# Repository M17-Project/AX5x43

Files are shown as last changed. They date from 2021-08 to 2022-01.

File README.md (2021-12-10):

# AX5x43
Test boards for the ON Semiconductor AX5043 and AX5243 RF transceiver chips.
#### The main purpose of this board is to test AX5x43's M17 support.

### Main differences between our board and other available out there
There are two major differences:
- the PWRAMP (AX5043) or TCXO_EN (AX5243) pin can be used as a sigma-delta modulator output for analog demodulation
- GPADC1 and GPADC2 pins can be used for analog frequency modulation (a VCO mode, if you will)

Note: There are no additional operational amplifiers nor filters in our design. Both modulator input and output are available at the pin header. ADC inputs can work in both differential and single-ended modes. Refer to the application note [AND9313/D](https://www.onsemi.com/pub/collateral/and9313-d.pdf).

### AX5043 PCB
PCB

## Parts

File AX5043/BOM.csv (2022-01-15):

References | Qty | Description | Manufacturer | MPN
C1 | 1 | 10pF 0603 | Yageo | CC0603JRNPO9BN100
C2 | 1 | 6.8pF 0603 | Yageo | CC0603DRNPO9BN6R8
C3 C4 | 2 | 100pF 0603 | Yageo | CC0603JRNPO9BN101
C5 C6 | 2 | 4.3pF 0603 | Yageo | CC0603CRNPO9BN4R3
C7 | 1 | 11pF 0603 | Yageo | CC0603JPNPO9BN110
C8 | 1 | 5.6pF 0603 | Yageo | CC0603DRNPO9BN5R6
C9 | 1 | 5.1pF 0603 | Yageo | CC0603CRNPO9BN5R1
C10 C12 C15 | 3 | 10nF 0603 | Yageo | CC0603KRX7R9BB103
C11 C13 | 2 | 100nF 0603 | Yageo | CC0603KRX7R9BB104
C14 | 1 | 39pF 0603 | Yageo | CC0603JRNPO9BN390
JP1 | 1 | CPL-CON-HEADER-THT-MALE
R1 R2 | 2 | 100nH 0603 | Murata | LQW18ASR10G00D
R3 R4 | 2 | 43nH 0603 | Murata | LQW18AN43NG00D
R5 R6 | 2 | 27nH 0603 | Murata | LQW18AN27NG00D
R9 | 1 | 6.8nH 0603 | Murata | LQW18AN6N8C00D
R10 | 1 | 12k 0603 | Yageo | RC0603FR-0712KL
U1 | 1 | AX5043 | onsemi | AX5043-1-TW30
X1 | 1 | 12MHz TCXO 2520 | ECS | ECS-TXO-2520MV-120-AY-TR
X2 | 1 | SMA female connector PCB edge mount | RF Solutions | CON-SMA-EDGE-S

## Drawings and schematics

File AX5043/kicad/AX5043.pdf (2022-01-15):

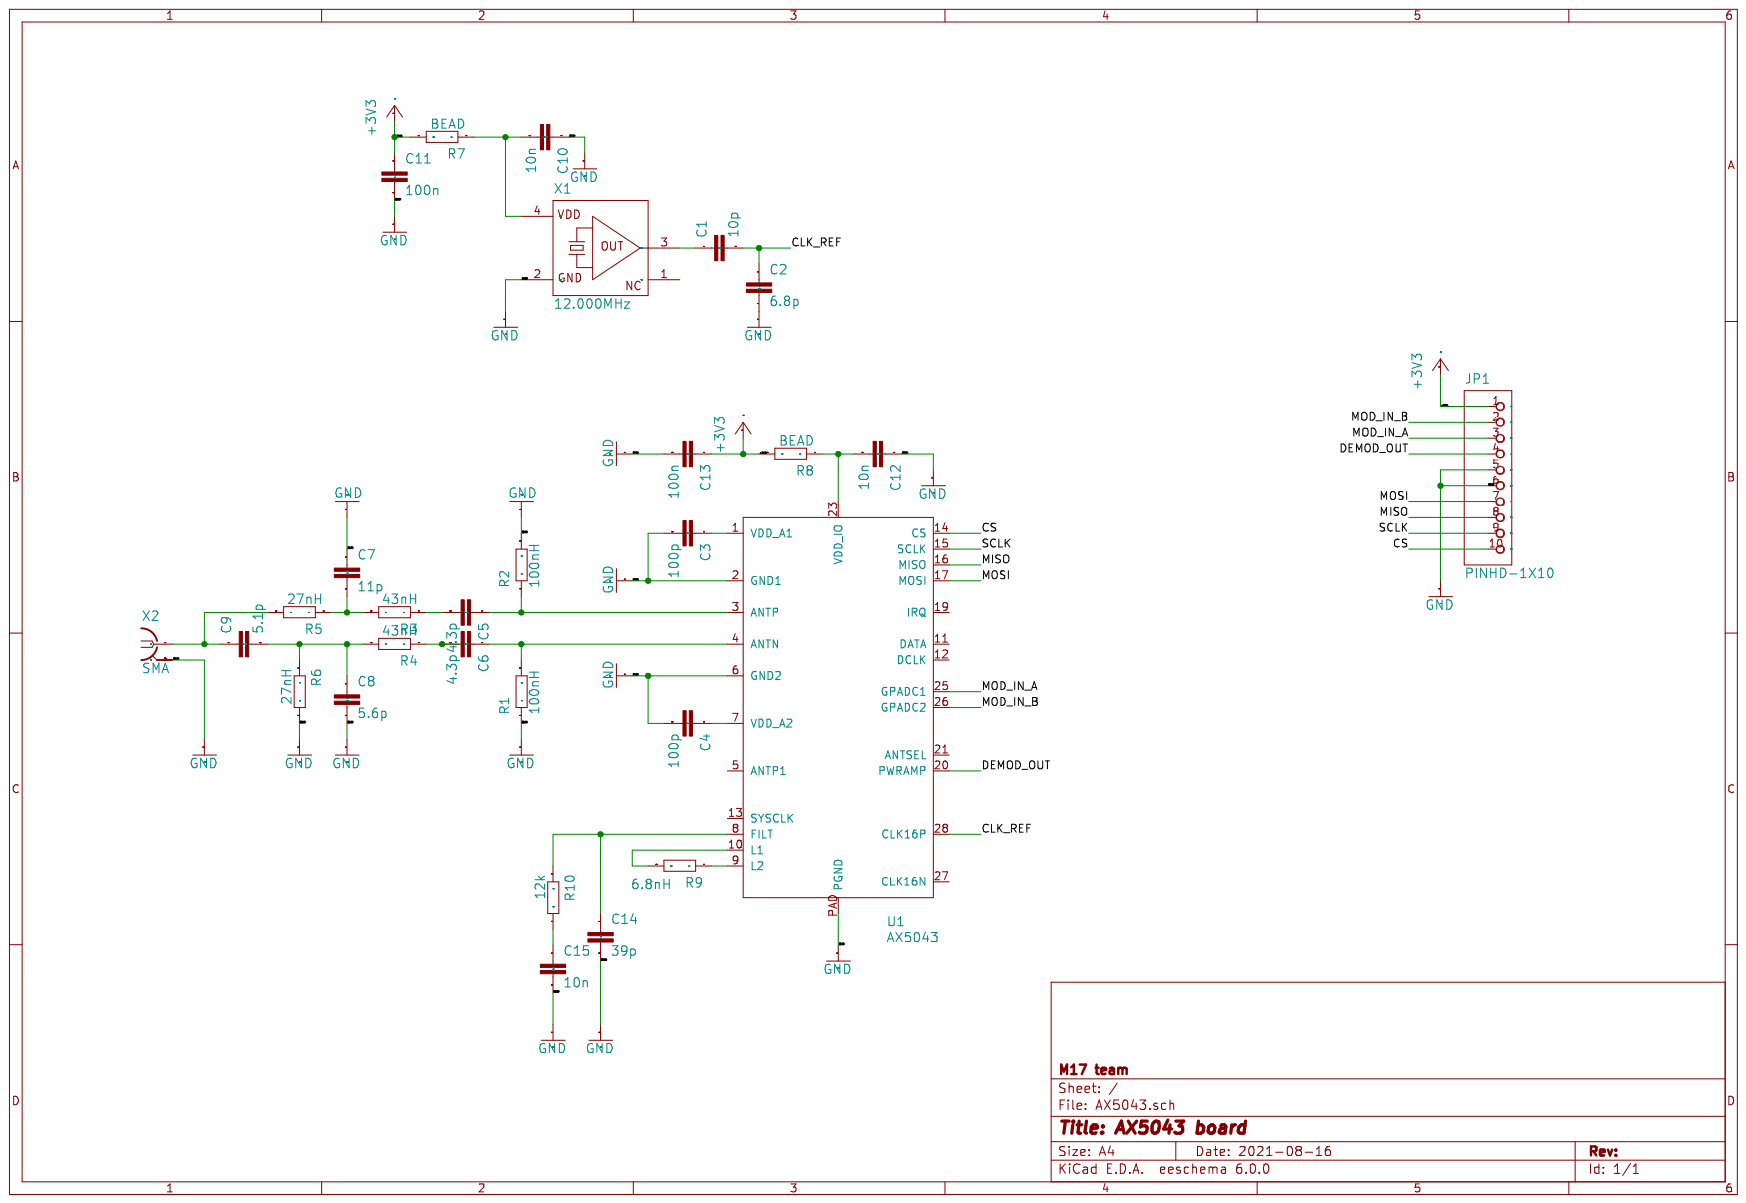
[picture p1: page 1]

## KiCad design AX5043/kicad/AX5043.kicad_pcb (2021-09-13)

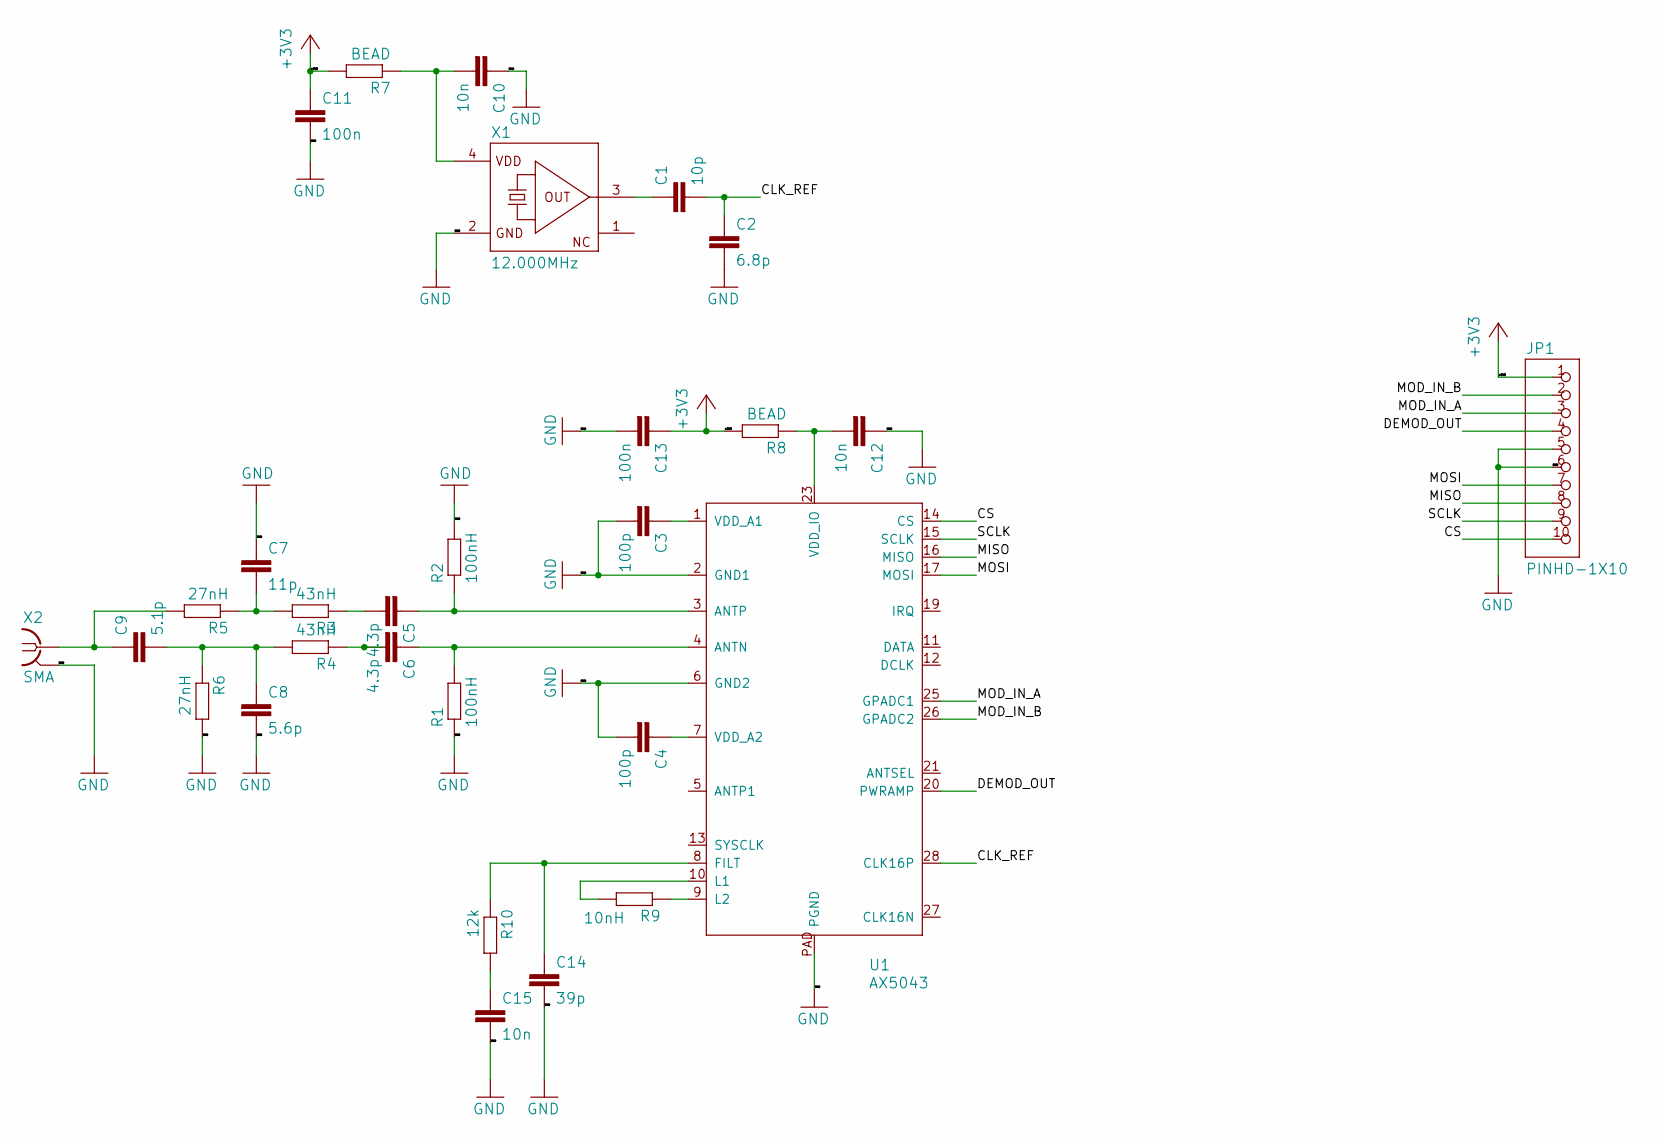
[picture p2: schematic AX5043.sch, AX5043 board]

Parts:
C1: 10p; C0603
C2: 6.8p; C0603
C3, C4: 100p; C0603
C5, C6: 4.3p; C0603
C7: 11p; C0603
C8: 5.6p; C0603
C9: 5.1p; C0603
C10, C12, C15: 10n; C0603
C11, C13: 100n; C0603
C14: 39p; C0603
JP1: PINHD-1X10; 1X10
R1, R2: 100nH; R0603
R3, R4: 43nH; R0603
R5, R6: 27nH; R0603
R7, R8: BEAD; R0603
R9: 10nH; R0603
R10: 12k; R0603
U1: AX5043; QFN28-5X5-WITH-CENTER-PAD
X1: 12.000MHz; ECS-TXO-2520
X2: SMA; J502-ND-142-0711-821_826

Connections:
+3V3: C11.1, C13.1, JP1.1, R7.2, R8.2
/CLK_REF: C1.2, C2.1, U1.28 (CLK16P)
/CS: JP1.10, U1.14 (CS)
/DEMOD_OUT: JP1.4, U1.20 (PWRAMP)
/MISO: JP1.8, U1.16 (MISO)
/MOD_IN_A: JP1.3, U1.25 (GPADC1)
/MOD_IN_B: JP1.2, U1.26 (GPADC2)
/MOSI: JP1.7, U1.17 (MOSI)
/SCLK: JP1.9, U1.15 (SCLK)
GND: C2.2, C3.2, C4.2, C7.1, C8.2, C10.1, C11.2, C12.1, C13.2, C14.2, C15.2, JP1.5, JP1.6, R1.1, R2.2, R6.2, U1.2 (GND1), U1.6 (GND2), U1.PAD (PGND), X1.2 (GND), X2.G@1 (2), X2.G@2 (2), X2.G@3 (2), X2.G@4 (2)
unnamed: C1.1, X1.3 (OUT)
unnamed: C3.1, U1.1 (VDD_A1)
unnamed: C4.1, U1.7 (VDD_A2)
unnamed: C5.1, R2.1, U1.3 (ANTP)
unnamed: C5.2, R3.1
unnamed: C6.1, R1.2, U1.4 (ANTN)
unnamed: C6.2, R4.1
unnamed: C7.2, R3.2, R5.1
unnamed: C8.1, C9.2, R4.2, R6.1
unnamed: C9.1, R5.2, X2.1
unnamed: C10.2, R7.1, X1.4 (VDD)
unnamed: C12.2, R8.1, U1.23 (VDD_IO)
unnamed: C14.1, R10.1, U1.8 (FILT)
unnamed: C15.1, R10.2
unnamed: R9.1, U1.9 (L2)
unnamed: R9.2, U1.10 (L1)

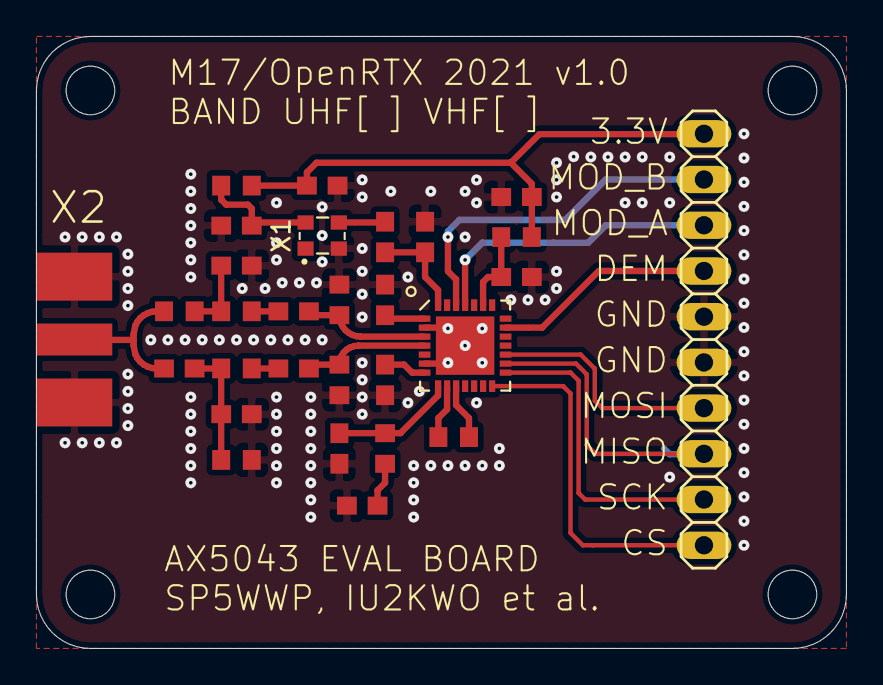
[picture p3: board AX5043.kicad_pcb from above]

Board: 2 copper layers, 45.0 x 34.0 mm, 29 parts (0 on the bottom side), 26 nets.

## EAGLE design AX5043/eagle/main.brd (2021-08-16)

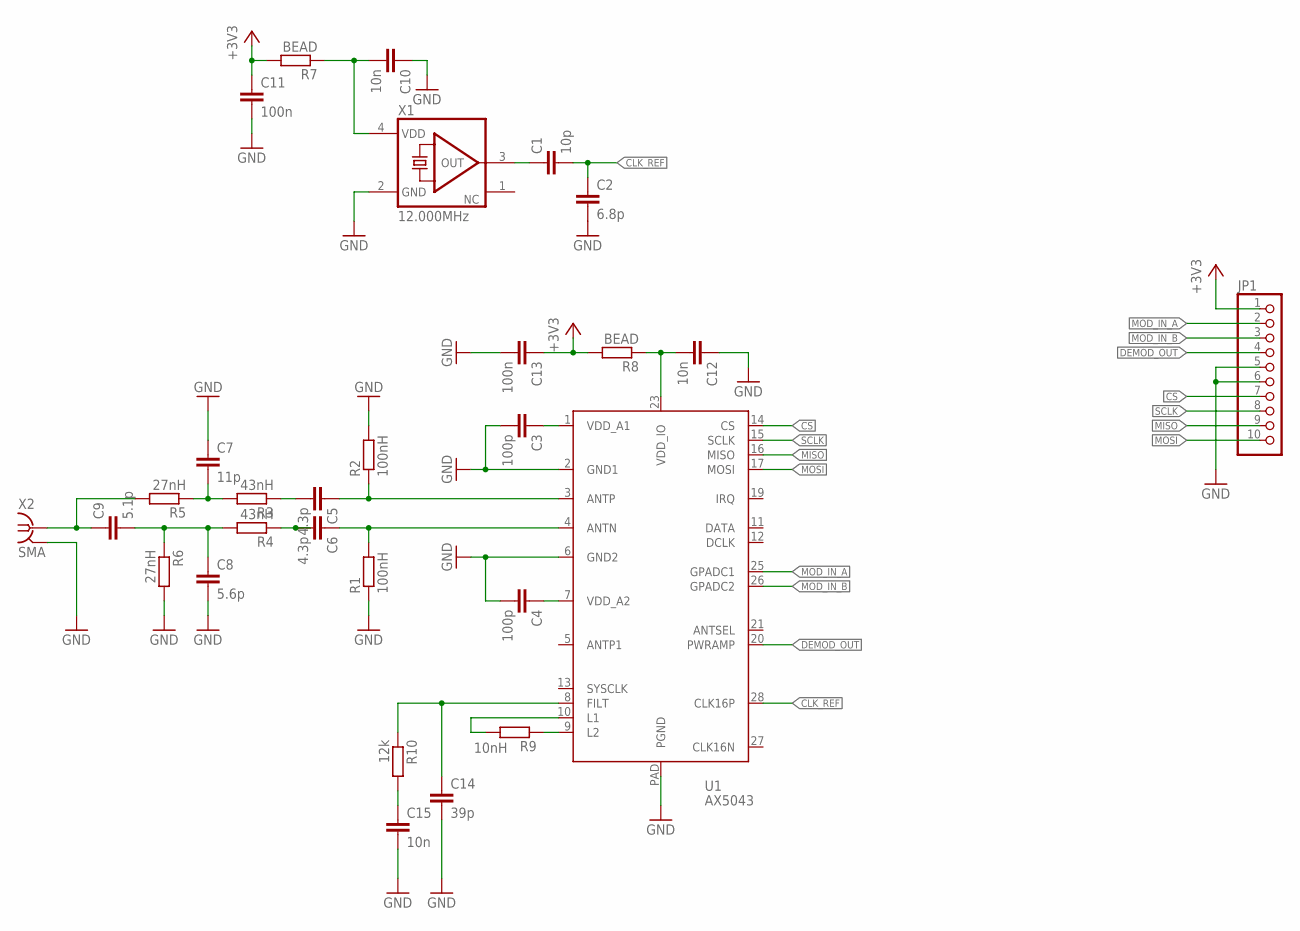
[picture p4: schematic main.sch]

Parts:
C1: 10p; C0603
C2: 6.8p; C0603
C3, C4: 100p; C0603
C5, C6: 4.3p; C0603
C7: 11p; C0603
C8: 5.6p; C0603
C9: 5.1p; C0603
C10, C12, C15: 10n; C0603
C11, C13: 100n; C0603
C14: 39p; C0603
JP1: PINHD-1X10; 1X10
R1, R2: 100nH; R0603
R3, R4: 43nH; R0603
R5, R6: 27nH; R0603
R7, R8: BEAD; R0603
R9: 10nH; R0603
R10: 12k; R0603
U1: AX5043; QFN28-5X5-WITH-CENTER-PAD
X1: 12.000MHz; ASE
X2: SMA; J502-ND-142-0711-821/826

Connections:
+3V3: C11.1, C13.1, JP1.1, R7.2, R8.2
CLK_REF: C1.2, C2.1, U1.28 (CLK16P)
CS: JP1.7, U1.14 (CS)
DEMOD_OUT: JP1.4, U1.20 (PWRAMP)
GND: C2.2, C3.2, C4.2, C7.1, C8.2, C10.1, C11.2, C12.1, C13.2, C14.2, C15.2, JP1.5, JP1.6, R1.1, R2.2, R6.2, U1.2 (GND1), U1.6 (GND2), U1.PAD (PGND), X1.2 (GND), X2.G@1 (2), X2.G@2 (2), X2.G@3 (2), X2.G@4 (2)
MISO: JP1.9, U1.16 (MISO)
MOD_IN_A: JP1.2, U1.25 (GPADC1)
MOD_IN_B: JP1.3, U1.26 (GPADC2)
MOSI: JP1.10, U1.17 (MOSI)
unnamed: C5.1, R2.1, U1.3 (ANTP)
unnamed: C6.1, R1.2, U1.4 (ANTN)
unnamed: C12.2, R8.1, U1.23 (VDD_IO)
unnamed: C6.2, R4.1
unnamed: C4.1, U1.7 (VDD_A2)
unnamed: C3.1, U1.1 (VDD_A1)
unnamed: C1.1, X1.3 (OUT)
unnamed: C5.2, R3.1
unnamed: C10.2, R7.1, X1.4 (VDD)
unnamed: C8.1, C9.2, R4.2, R6.1
unnamed: C7.2, R3.2, R5.1
unnamed: C9.1, R5.2, X2.1
unnamed: R9.1, U1.9 (L2)
unnamed: R9.2, U1.10 (L1)
unnamed: C14.1, R10.1, U1.8 (FILT)
unnamed: C15.1, R10.2
SCLK: JP1.8, U1.15 (SCLK)

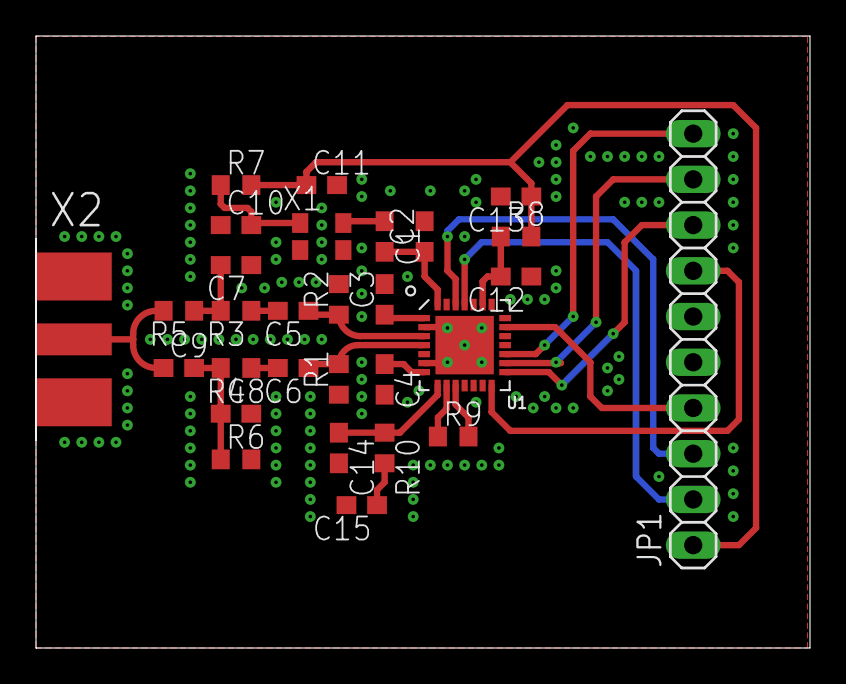
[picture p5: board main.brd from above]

Board: 2 copper layers, 43.0 x 34.0 mm, 29 parts (0 on the bottom side), 26 nets.

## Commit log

2021-08-16 Eagle and KiCad project files
    [AX5043.kicad_pcb, AX5043.sch, main.brd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]
2021-08-24 Rescued some missing symbols/footprint in KiCad project
    [AX5043.sch]
2021-08-24 Add rounded corners
    [AX5043.kicad_pcb]
2021-09-09 Reorganised KiCad libraries
    [AX5043.kicad_pcb, AX5043.sch]
2021-09-09 New footprint for TCXO, model is ECS-TXO-2520
    [AX5043.kicad_pcb, AX5043.sch]
2021-09-13 Gerber files for PCB manufacturing
    [AX5043-B_Mask.gbr, AX5043-B_SilkS.gbr, AX5043-Bottom.gbr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]
2021-09-13 Fixed some unconnected ground vias, re-generated gerber files
    [AX5043-B_Mask.gbs, AX5043-B_Paste.gbp, AX5043-B_SilkS.gbo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]
2021-09-13 Removed dangling trace, re-generated gerber files
    [AX5043-B_Mask.gbs, AX5043-B_Paste.gbp, AX5043-B_SilkS.gbo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]
2021-10-31 Added folder for AX5243 board, moved AX5043 files to a dedicated folder
    [AX5043-B_Mask.gbs, AX5043-B_Paste.gbp, AX5043-B_SilkS.gbo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]
2022-01-15 Changed value of VCO coil inductor from 10nH to 6.8nH. Added BOM.
    [AX5043.sch, BOM.csv, ax5243_eval.sch]
